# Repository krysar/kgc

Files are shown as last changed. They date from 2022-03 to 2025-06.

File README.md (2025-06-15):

# Kerbal Guidance Computer

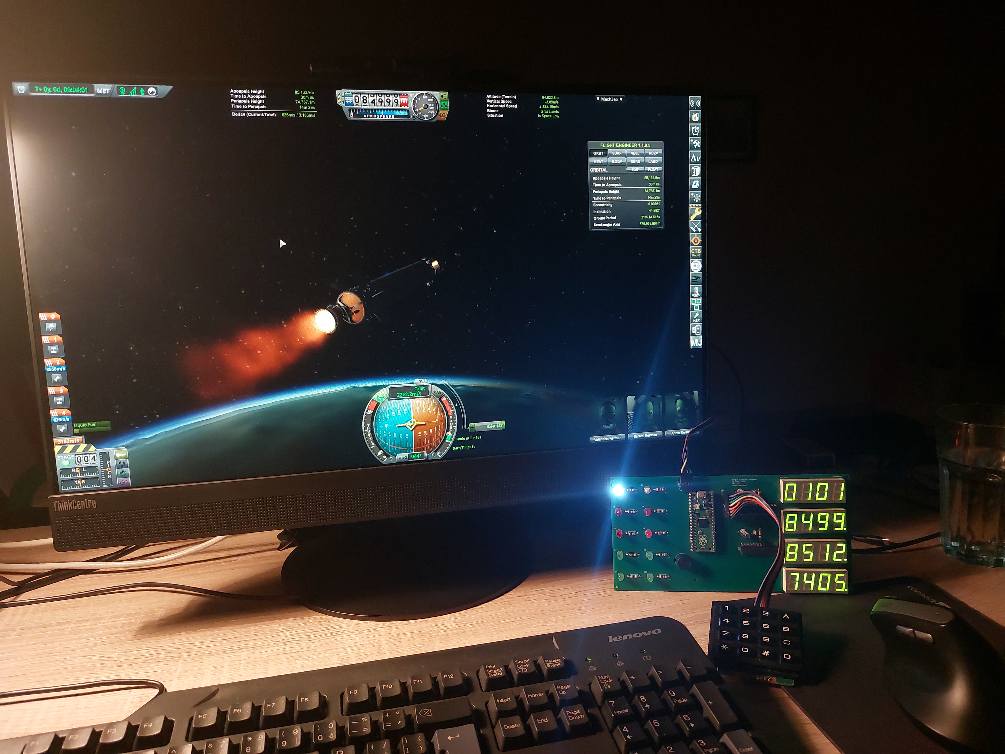
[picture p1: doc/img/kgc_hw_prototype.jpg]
KGC DSKY HW prototype of KGC's DSKY


A HW flight computer for Kerbal Space Program inspired by NASA's DSKY - interface for [Apollo Guidance Computer](https://en.wikipedia.org/wiki/Apollo_Guidance_Computer).

It consists of Python script for PC which grab data from the [kRPC mod](https://krpc.github.io/krpc/index.html), KGC's DSKY based on Raspberry Pi Pico and program for it. DSKY communicate with PC via UART, so you also need some USB-UART converter. KiCad project for DSKY is located in kicad directory.

**Project is still in developement, it's pretty buggy and some of planned features are stil unimplemented.**

## Features
### Implemented
- Display several flight informations depending on selected Verb and Noun.
- Ship control:
    - SAS control
    - RCS control
    - Gear control
    - Lights control
    - Brakes control
    - Solar panels control (extend/retract)
    - Antennas control (extend/retract)
    - Next stage activation
    - Abort group activation
- Maneuver planning
- MechJeb control:
    - Ascent guidance
### Planned
- Ship control:
    - Thrust control
- MechJeb control:
    - Landing guidance
    - Rendezvous autopilot
    - Docking autopilot
    - Maneuver planner

## Installation
TODO

## Usage
TODO

## Verbs and Nouns list

| Verb | Noun | Input/Output | Actions | Notes |
|---|---|---|---|---|
| 00 | 00 | | No op | |
| 01 | 01 | | Disconnect from server | |
| 00 | 02 | | Reboot | |
| 01 | 00 | | No op | |
| 01 | 01 | O: Altitude above sea level [m] | | |
| | | O: Apoapsis [m] | | |
| | | O: Periapsis [m] | | |
| 01 | 02 | O: Orbital inclination [°] | | |
| | | O: Orbital eccentricity [°] | | |
| | | O: Mean anomaly [°] | | |
| 01 | 03 | O: Time to apoapsis [hrs] | | |
| | | O: Time to apoapsis [min] | | |
| | | O: Time to apoapsis [sec] | | |
| 01 | 04 | O: Time to apoapsis [days] | | |
| | | O: Time to apoapsis [hrs] | | |
| | | O: Time to apoapsis [min] | | Kerbin days |
| 01 | 05 | O: Time to periapsis [hrs] | | |
| | | O: Time to periapsis [min] | | |
| | | O: Time to periapsis [sec] | | |
| 01 | 06 | O: Time to periapsis [days] | | |
| | | O: Time to periapsis [hrs] | | |
| | | O: Time to periapsis [min] | | Kerbin days |
| 01 | 07 | O: Orbital period [hrs] | | |
| | | O: Orbital period [min] | | |
| | | O: Orbital period [sec] | | |
| 01 | 08 | O: Orbital period [days] | | |
| | | O: Orbital period [hrs] | | |
| | | O: Orbital period [min] | | Kerbin days |
| 01 | 09 | O: Time to sphere of influence change [hrs]  | | |
| | | O: Time to sphere of influence change [min]  | | |
| | | O: Time to sphere of influence change [sec]  | | |
| 01 | 10 | O: Time to sphere of influence change [days] | | |
| | | O: Time to sphere of influence change [hrs]  | | |
| | | O: Time to sphere of influence change [min]  | | Kerbin days |
| 01 | 11 | O: Heading [°] | | TODO: check ref. frame |
| | | O: Pitch [°] | | TODO: check ref. frame |
| | | O: Roll [°] | | TODO: check ref. frame |
| 01 | 12 | O: Velocity - x [m/s] | | TODO: check ref. frame |
| | | O: Velocity - y [m/s] | | |
| | | O: Velocity - z [m/s] | | |
| 01 | 13 | O: Orbital speed [m/s] | | |
| | | O: Surface speed [m/s] | | |
| 02 | 00 | | No op | |
| 02 | 01 | O: Mission elapsed time [hrs] | | |
| | | O: Mission elapsed time [min] | | |
| | | O: Mission elapsed time [sec] | | Strange bug |
| 02 | 02 | O: Mission elapsed time [days] | | |
| | | O: Mission elapsed time [min] | | Strange bug |
| | | O: Mission elapsed time [hrs] | | Strange bug |
| 02 | 03 | O: Mass [kg] | | |
| | | O: Available thurst [N] | | |
| | | O: Specific impulse [sec] | | |
| 02 | 04 | O: Electric charge capacity [-] | | |
| | | O: Monopropellant capacity [-] | | |
| | | O: Liquid fuel capacity [-] | | |
| 02 | 05 | O: Electric charge amount [-] | | TODO: float |
| | | O: Monopropellant amount [-] | | TODO: float |
| | | O: Liquid fuel amount [-] | | TODO: float |
| 02 | 06 | O: Electric charge amount [%] | | |
| | | O: Monopropellant amount [%] | | |
| | | O: Liquid fuel amount [%] | | |
| 02 | 07 | O: Electric charge capacity [-] | | |
| | | O: Electric charge amount [-] | | TODO: float |
| | | O: Electric charge amount [%] | | |
| 02 | 08 | O: Monopropellant capacity [-] | | |
| | | O: Monopropellant amount [-] | | TODO: float |
| | | O: Monopropellant amount [%] | | |
| 02 | 09 | O: Liquid fuel capacity [-] | | |
| | | O: Liquid fuel amount [-] | | TODO: float |
| | | O: Liquid fuel amount [%] | | |
| 03 | 01 | O: Surface speed [m/s] | | |
| | | O: Vertical speed [m/s] | | |
| | | O: Altitude above surface [m] | | |
| 03 | 02 | O: Altitude above sea level | | |
| | | O: Apoapsis [m] | | |
| | | O: Orbital inclination [°] | | |
| 03 | 03 | O: Apoapsis [m] | | |
| | | O: Periapsis [m] | | |
| | | O: Orbital inclination [°] | | |
| 04 | 01 | O: Time to node [hrs] | | |
| | | O: Time to node [min] | | |
| | | O: Time to node [sec] | | |
| 04 | 02 | O: Δv magnitude - prograde direction [m/s] | | |
| | | O: Δv magnitude - normal direction [m/s] | | |
| | | O: Δv magnitude - radial direction [m/s] | | |
| 04 | 03 | O: Δv [m/s] | | |
| | | O: Remaining Δv [m/s] | | |
| | | O: Time to node [sec] | | |
| 04 | 04 | O: Result apoapsis [m] | | |
| | | O: Result periapsis [m] | | |
| | | O: Result inclination [°] | | |
| 05 | 01 | O: Altitude above surface [m] | | |
| | | O: Surface speed [m/s] | | |
| | | O: Liquid fuel amount [%] | | |
| 05 | 02 | O: Altitude above surface [m] | | |
| | | O: Vertical speed [m/s] | | |
| | | O: Horizontal speed [m/s] | | |
| 12 | 01 | | Activate SAS in stability assist mode | Then return to previous Verb + Noun |
| 12 | 02 | | Activate SAS in maneuver mode | Then return to previous Verb + Noun |
| 12 | 03 | | Activate SAS in prograde mode | Then return to previous Verb + Noun |
| 12 | 04 | | Activate SAS in retrograde mode | Then return to previous Verb + Noun |
| 12 | 05 | | Activate SAS in normal mode | Then return to previous Verb + Noun |
| 12 | 06 | | Activate SAS in anti-normal mode | Then return to previous Verb + Noun |
| 12 | 07 | | Activate SAS in radial mode | Then return to previous Verb + Noun |
| 12 | 08 | | Activate SAS in anti-radial mode | Then return to previous Verb + Noun |
| 12 | 09 | | Activate SAS in target mode | Then return to previous Verb + Noun |
| 12 | 10 | | Activate SAS in anti-targer mode | Then return to previous Verb + Noun |
| 12 | 11 | | Deactivate SAS | Then return to previous Verb + Noun |
| 12 | 12 | | Activate RCS | Then return to previous Verb + Noun |
| 12 | 13 | | Deactivate RCS | Then return to previous Verb + Noun |
| 12 | 14 | | Extend gear | Then return to previous Verb + Noun |
| 12 | 15 | | Retract gear | Then return to previous Verb + Noun |
| 12 | 16 | | Activate ligts | Then return to previous Verb + Noun |
| 12 | 17 | | Deactivate lights | Then return to previous Verb + Noun |
| 12 | 18 | | Activate brakes | Then return to previous Verb + Noun |
| 12 | 19 | | Deactivate brakes | Then return to previous Verb + Noun |
| 12 | 20 | | Extend solar panels | Then return to previous Verb + Noun |
| 12 | 21 | | Retract solar panels | Then return to previous Verb + Noun |
| 12 | 22 | | Extend antennas | Then return to previous Verb + Noun |
| 12 | 23 | | Retract antennas | Then return to previous Verb + Noun |
| 12 | 24 | | Activate next stage | Then return to previous Verb + Noun |
| 12 | 25 | | Activate abort group | Then return to previous Verb + Noun |
| 12 | 30 | | Initialize node creation | |
| 12 | 31 | I: UT - year | | |
| | | I: UT - day | | |
| 12 | 32 | O: UT - year | | |
| | | O: UT - day | | |
| 12 | 33 | I: UT - hour | | |
| | | I: UT - minute | | |
| | | I: UT - second | | |
| 12 | 34 | O: UT - hour | | |
| | | O: UT - minute | | |
| | | O: UT - second | | |
| 12 | 35 | I: Δv - prograde [m/s] | | |
| | | I: Δv - normal [m/s] | | |
| | | I: Δv - radial [m/s] | | |
| 12 | 36 | O: Δv - prograde [m/s] | | |
| | | O: Δv - normal [m/s] | | |
| | | O: Δv - radial [m/s] | | |
| 12 | 37 | | Create node | Incorrect time |
| 13 | 00 | | Initialize ascent autpoilot | MechJeb is used |
| 13 | 01 | I: Orbit altitude [km] | | |
| | | I: Orbit inclination [°] | | |
| | | I: Ascent profile {1; 2; 3} | | 1 = Classic ascent profile |
| | | | | 2 = Stock-style GravityTurn ascent profile |
| | | | | 3 = Primer Vector Guidance ascent profile |
| 13 | 02 | O: Orbit altitude [km] | | |
| | | O: Orbit inclination [°] | | |
| | | O: Ascent profile {1; 2; 3} | | |
| 13 | 03 | I: Acceleration limit [m/s] | | -1 for disable; -2 for ignore |
| | | I: Throttle limit [%] | | -1 for disable; -2 for ignore |
| 13 | 04 | O: Acceleration limit [m/s] | | |
| | | O: Throttle limit [%] | | |
| 13 | 05 | I: Force roll - climb [°] | | -1 for disable; -2 for ignore (whole force roll) |
| | | I: Force roll - turn [°] | | |
| 13 | 06 | O: Force roll - climb [°] | | |
| | | O: Force roll - turn [°] | | |
| 13 | 07 | I: Autostage pre-delay [s] | | -1 for disable; -2 for ignore (whole autostage) |
| | | I: Autostage post-delay [s] | | |
| | | I: Clamp autostage thrust [%] | | |
| 13 | 08 | O: Autostage pre-delay [s] | | |
| | | O: Autostage post-delay [s] | | |
| | | O: Clamp autostage thrust [%] | | |
| 13 | 09 | I: Minimal throttle [%] | | -1 for disable; -2 for ignore |
| | | I: Autostage stop stage | | Details in truth table |
| | | I: Other options | | |
| 13 | 10 | O: Minimal throttle [%] | | |
| | | O: Autostage stop stage | | |
| | | O: Other options | | |
| 13 | 11 | I: Turn start altitude [km] | | Classic ascent profile |
| | | I: Turn start velocity [m/s] | | Classic ascent profile |
| | | I: Turn end altitude [km] | | Classic ascent profile |
| 13 | 12 | O: Turn start altitude [km] | | Classic ascent profile |
| | | O: Turn start velocity [m/s] | | Classic ascent profile |
| | | O: Turn end altitude [km] | | Classic ascent profile |
| 13 | 13 | I: Final flight path angle [°] | | Classic ascent profile; -1 for disable; -2 for ignore |
| | | I: Turn shape [%] | | Classic ascent profile; -1 for disable; -2 for ignore |
| 13 | 14 | O: Final flight path angle [°] | | Classic ascent profile |
| | | O: Turn shape [%] | | Classic ascent profile |
| 13 | 15 | I: Turn start altitude [km] | | Stock-style GravityTurn ascent profile |
| | | I: Turn start velocity [m/s] | | Stock-style GravityTurn ascent profile |
| | | I: Turn start pitch [°] | | Stock-style GravityTurn ascent profile |
| 13 | 16 | O: Turn start altitude [km] | | Stock-style GravityTurn ascent profile |
| | | O: Turn start velocity [m/s] | | Stock-style GravityTurn ascent profile |
| | | O: Turn start pitch [°] | | Stock-style GravityTurn ascent profile |
| 13 | 17 | I: Intermediate altitude [km] | | Stock-style GravityTurn ascent profile |
| | | I: Hold AP time [s] | | Stock-style GravityTurn ascent profile |
| 13 | 18 | O: Intermediate altitude [km] | | Stock-style GravityTurn ascent profile |
| | | O: Hold AP time [s] | | Stock-style GravityTurn ascent profile |
| 13 | 19 | I: Apoapsis altitude [km] | | Primer Vector Guidance ascent profile |
| | | I: Attach altitude [km] | | Primer Vector Guidance ascent profile |
| | | I: Booster pitch start velocity [m/s] | | Primer Vector Guidance ascent profile |
| 13 | 20 | O: Apoapsis altitude [km] | | Primer Vector Guidance ascent profile |
| | | O: Attach altitude [km] | | Primer Vector Guidance ascent profile |
| | | O: Booster pitch start velocity [m/s] | | Primer Vector Guidance ascent profile |
| 13 | 21 | I: Booster pitch rate [°/s] | | Primer Vector Guidance ascent profile |
| | | I: PVG after stage | | Primer Vector Guidance ascent profile; -1 for disable; -2 for ignore |
| 13 | 22 | O: Booster pitch rate [°/s] | | Primer Vector Guidance ascent profile |
| | | O: PVG after stage | | Primer Vector Guidance ascent profile |
| 13 | 23 | I: Q trigger [kPa] | | Primer Vector Guidance ascent profile |
| | | I: Fixed coast length [s] | | Primer Vector Guidance ascent profile; -1 for disable; -2 for ignore |
| 13 | 24 | O: Q trigger [kPa] | | Primer Vector Guidance ascent profile |
| | | O: Fixed coast length [s] | | Primer Vector Guidance ascent profile |
| 13 | 25 | | Enage ascent autopilot | |
| 13 | 26 | | Disenage ascent autopilot | |

## Truth table for other options value in Ascent autopilot

| Prevent overheat | Solar panels | Antennas | Skip circularization | Dec |
|---|---|---|---|-----|
| 0 | 0 | 0 | 0 | 0 |
| 0 | 0 | 0 | 1 | 1 |
| 0 | 0 | 1 | 0 | 2 |
| 0 | 0 | 1 | 1 | 3 |
| 0 | 1 | 0 | 0 | 4 |
| 0 | 1 | 0 | 1 | 5 |
| 0 | 1 | 1 | 0 | 6 |
| 0 | 1 | 1 | 1 | 7 |
| 1 | 0 | 0 | 0 | 8 |
| 1 | 0 | 0 | 1 | 9 |
| 1 | 0 | 1 | 0 | 10  |
| 1 | 0 | 1 | 1 | 11  |
| 1 | 1 | 0 | 0 | 12  |
| 1 | 1 | 0 | 1 | 13  |
| 1 | 1 | 1 | 0 | 14  |
| 1 | 1 | 1 | 1 | 15  |

## Error codes
### Ascent guidance:
- 1301: Noun doesn't exist
- 1302: Autopilot wasn't initialized
- 1303: Ascent profile selected in V13;N01 doesn't exist

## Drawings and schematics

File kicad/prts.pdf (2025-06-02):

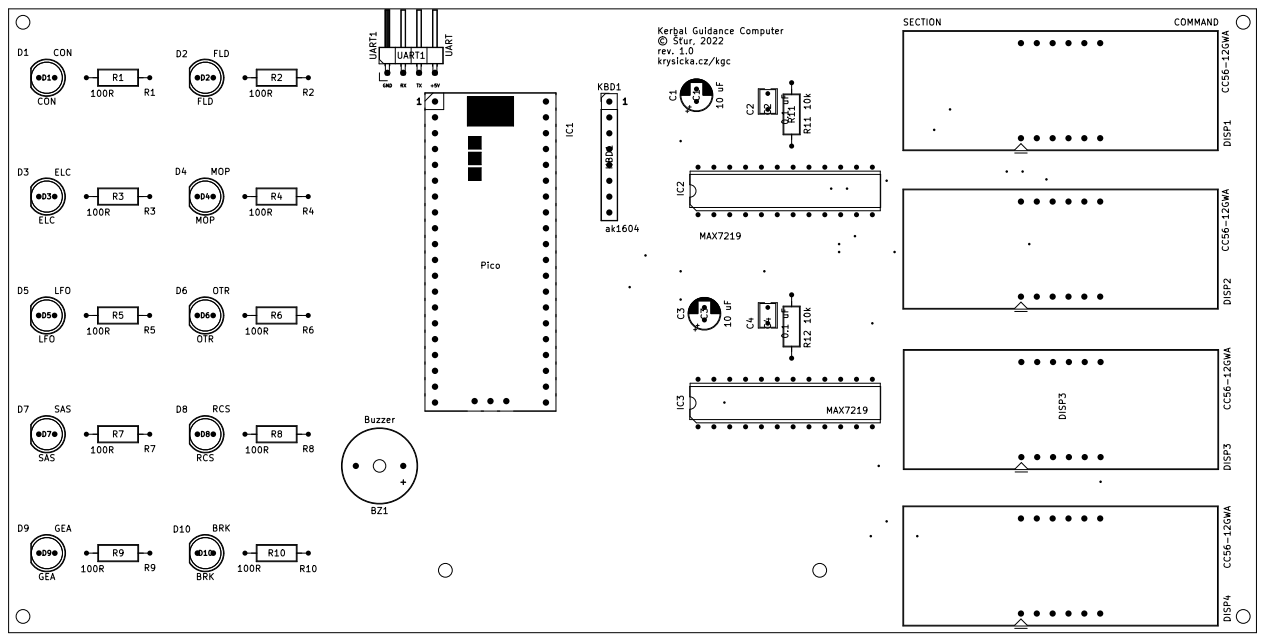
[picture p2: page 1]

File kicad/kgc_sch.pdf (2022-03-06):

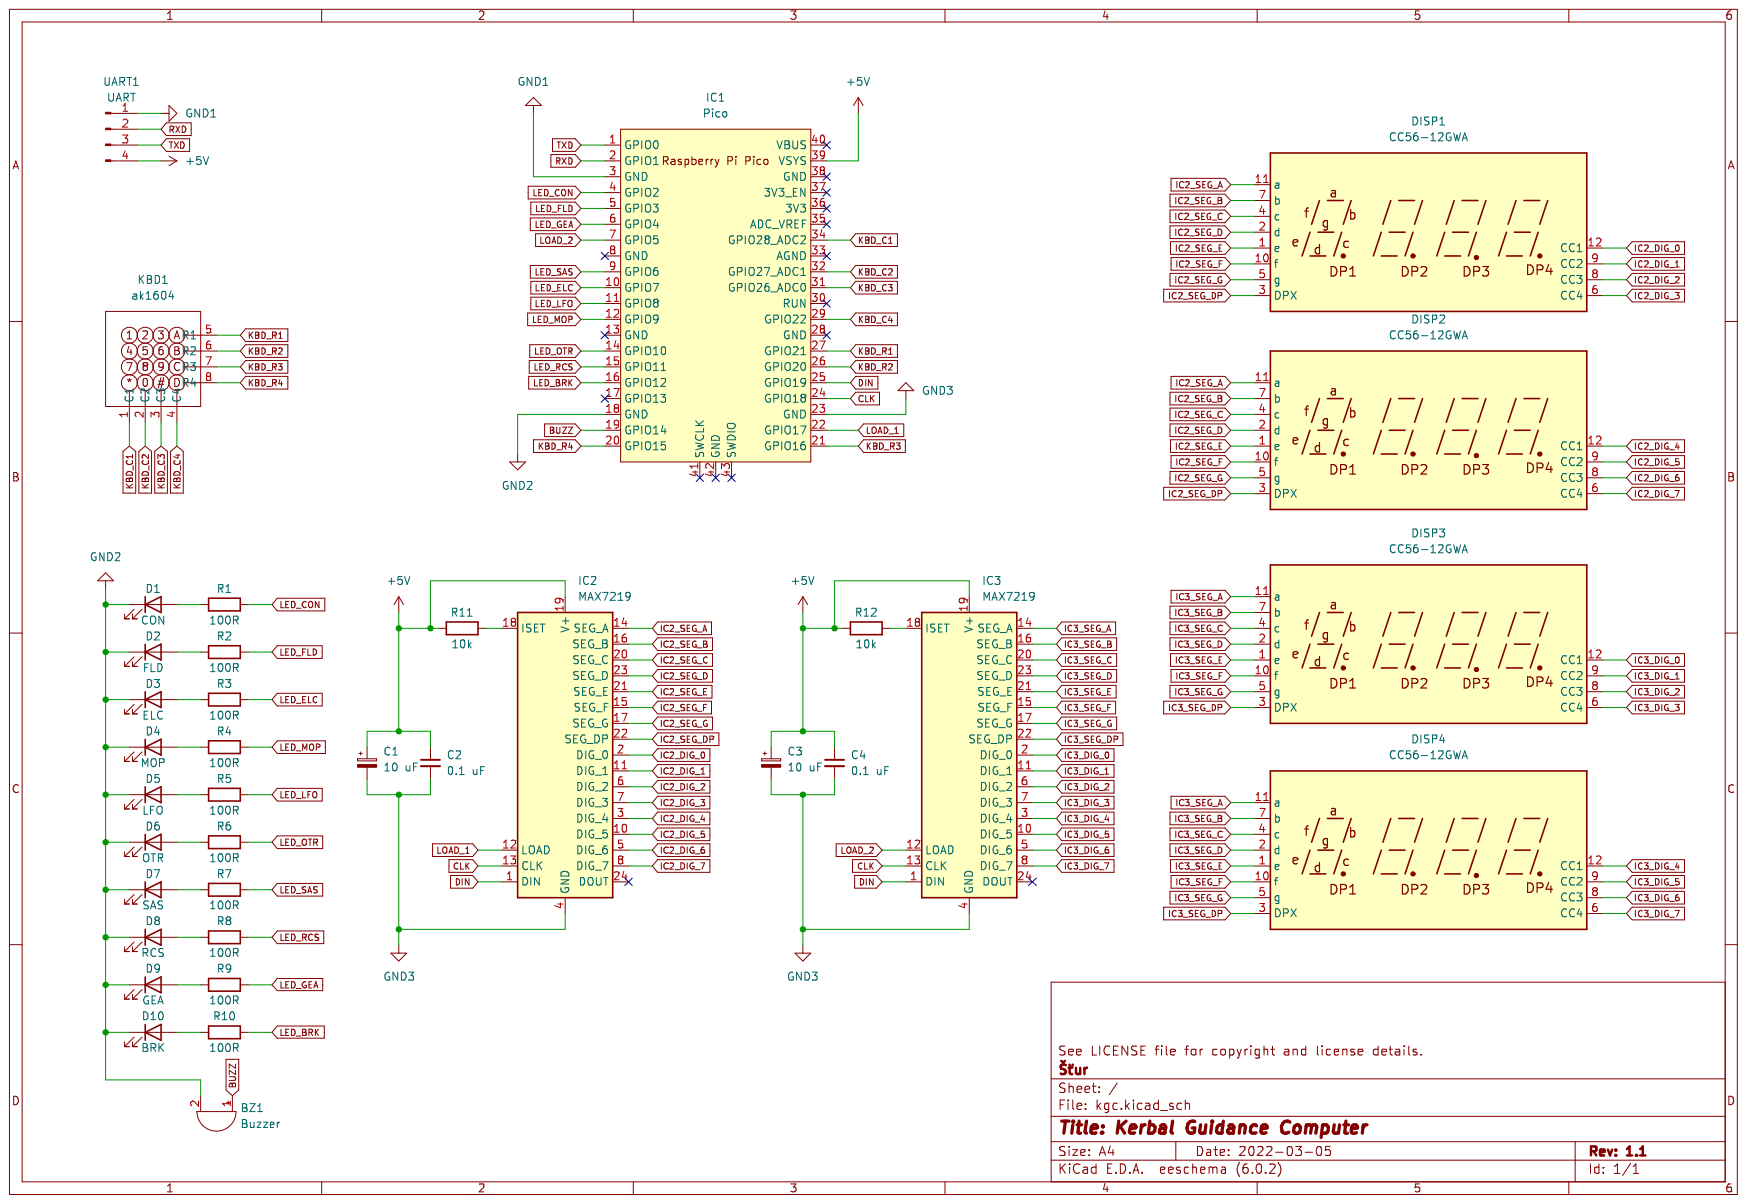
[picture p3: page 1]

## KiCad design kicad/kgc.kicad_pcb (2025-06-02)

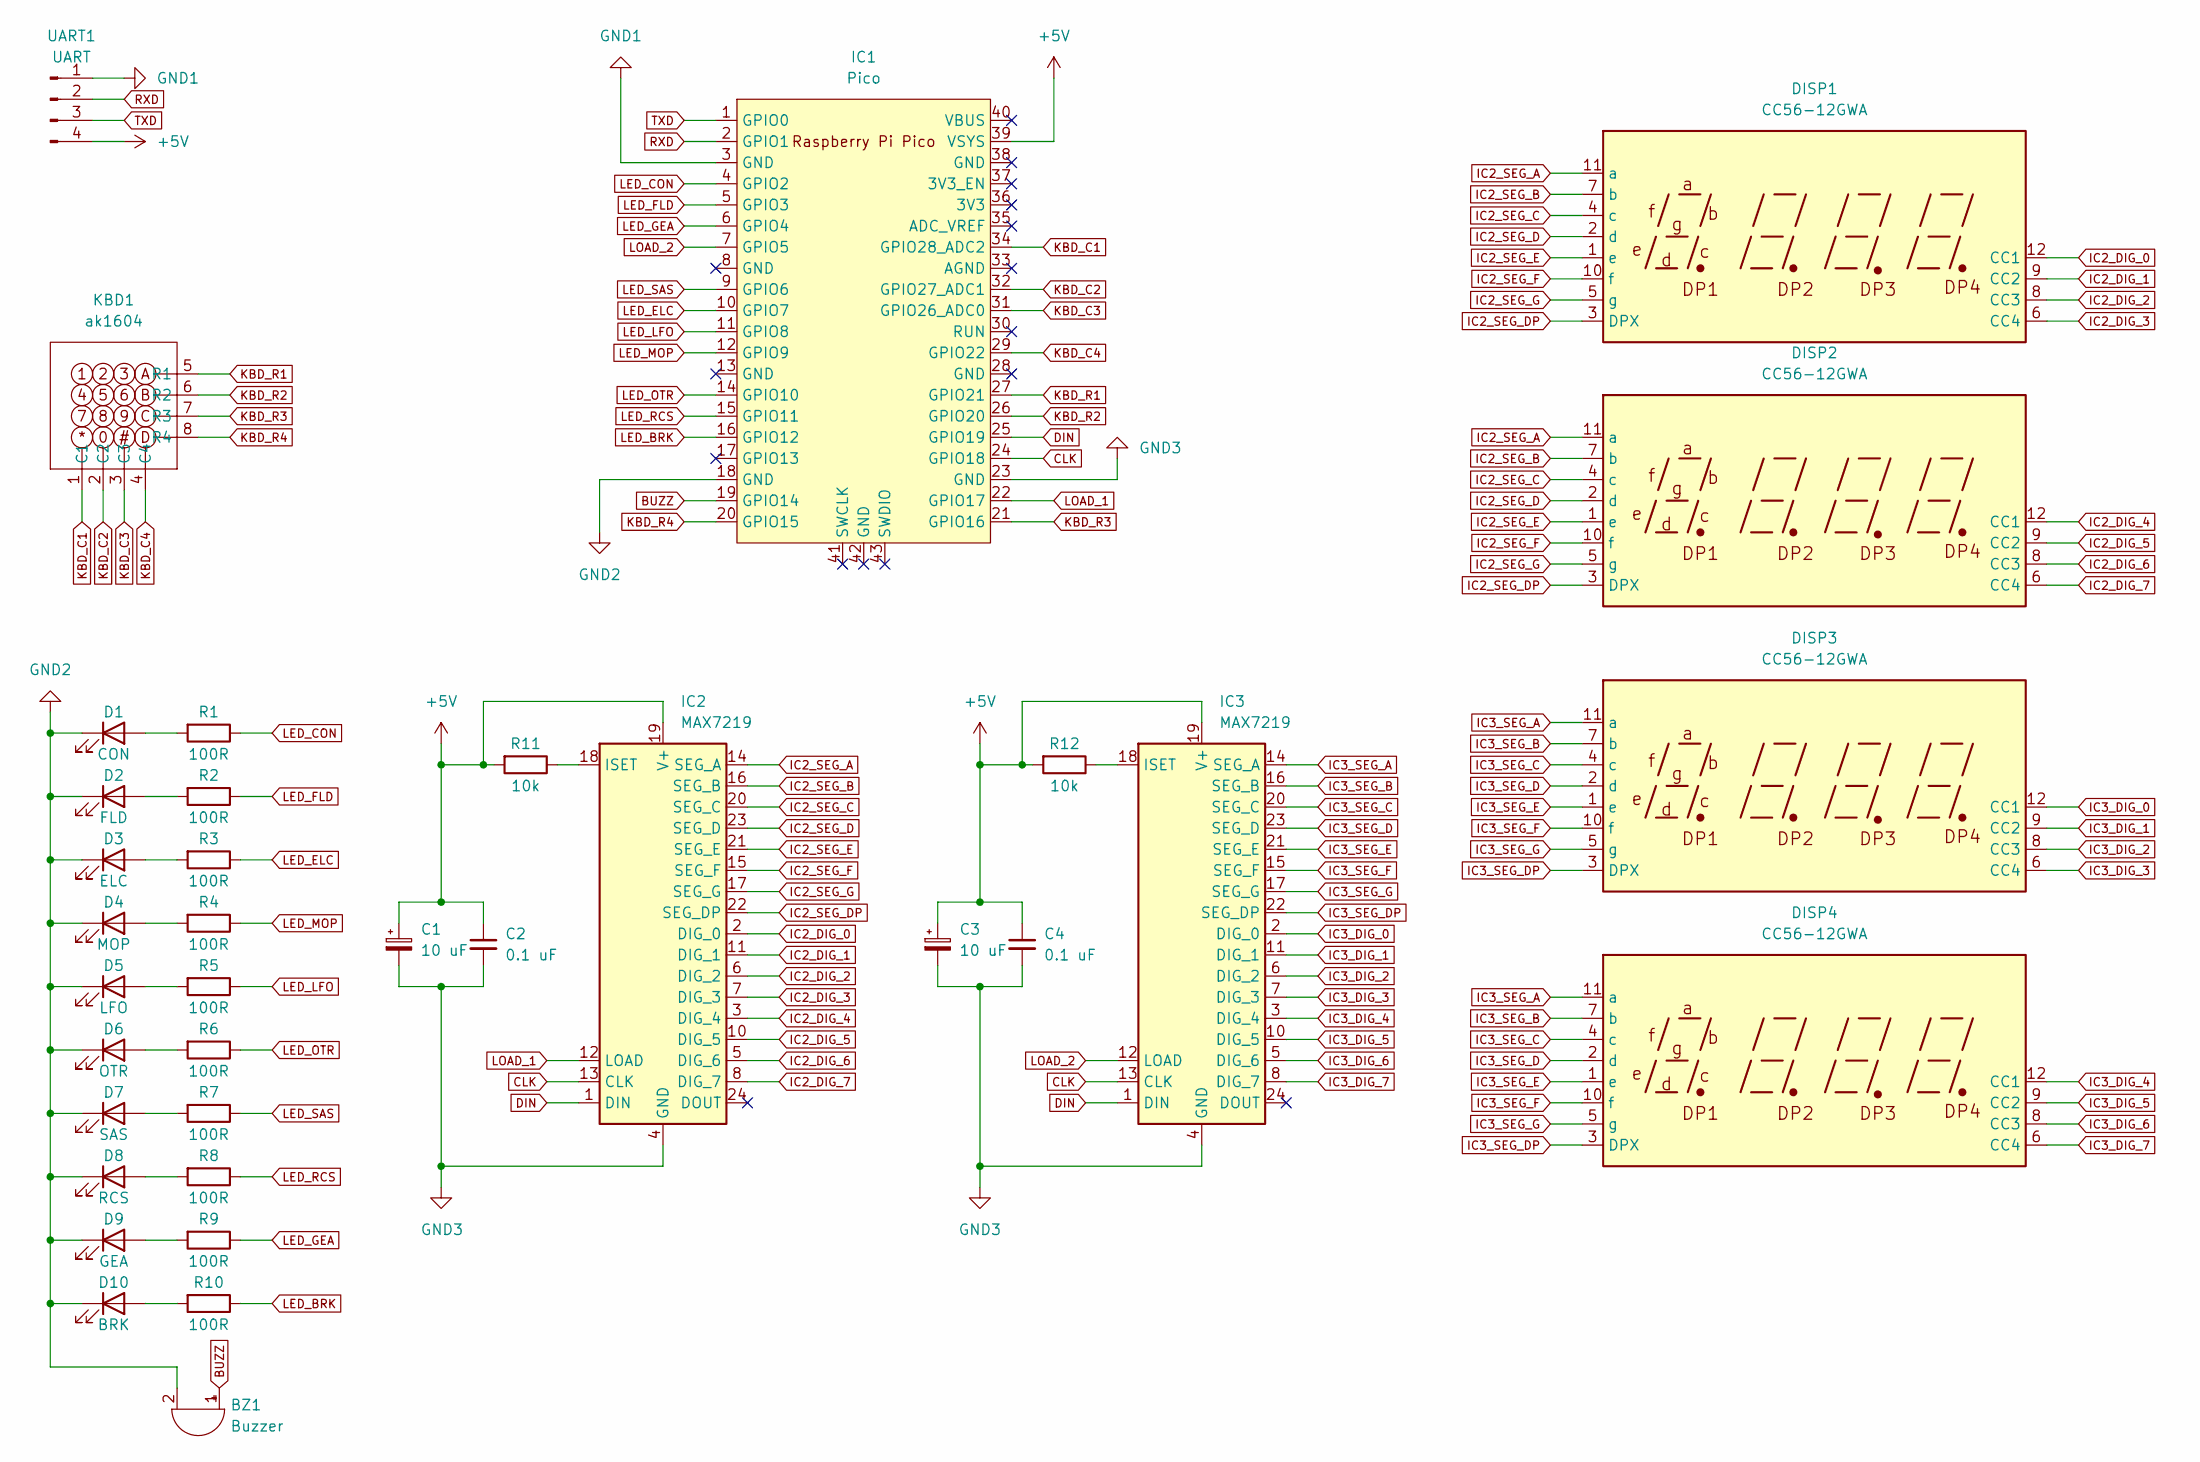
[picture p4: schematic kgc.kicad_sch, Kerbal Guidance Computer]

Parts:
BZ1: Buzzer; Buzzer_12x9.5RM7.6
C1, C3: 10 uF; CP_Radial_D5.0mm_P2.00mm
C2, C4: 0.1 uF; C31x
D1: CON; LED_D5.0mm
D2: FLD; LED_D5.0mm
D3: ELC; LED_D5.0mm
D4: MOP; LED_D5.0mm
D5: LFO; LED_D5.0mm
D6: OTR; LED_D5.0mm
D7: SAS; LED_D5.0mm
D8: RCS; LED_D5.0mm
D9: GEA; LED_D5.0mm
D10: BRK; LED_D5.0mm
DISP1, DISP2, DISP3, DISP4: CC56-12GWA
IC1: Pico; RPi_Pico_TH
IC2, IC3: MAX7219; DIP-24_W7.62mm
KBD1: ak1604; PinHeader_1x08_P2.54mm_Vertical
R1, R2, R3, R4, R5, R6, R7, R8, R9, R10: 100R; R_Axial_DIN0207_L6.3mm_D2.5mm_P10.16mm_Horizontal
R11, R12: 10k; R_Axial_DIN0207_L6.3mm_D2.5mm_P10.16mm_Horizontal
UART1: UART; PinHeader_1x04_P2.54mm_Horizontal

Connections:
+5V: C1.1, C2.1, C3.1, C4.1, IC1.39 (VSYS), IC2.19 (V+), IC3.19 (V+), R11.2, R12.2, UART1.4
BUZZ: BZ1.1 (-), IC1.19 (GPIO14)
CLK: IC1.24 (GPIO18), IC2.13 (CLK), IC3.13 (CLK)
DIN: IC1.25 (GPIO19), IC2.1 (DIN), IC3.1 (DIN)
GND1: IC1.3 (GND), UART1.1
GND2: BZ1.2 (+), D1.1 (K), D2.1 (K), D3.1 (K), D4.1 (K), D5.1 (K), D6.1 (K), D7.1 (K), D8.1 (K), D9.1 (K), D10.1 (K), IC1.18 (GND)
GND3: C1.2, C2.2, C3.2, C4.2, IC1.23 (GND), IC2.4 (GND), IC2.9 (GND), IC3.4 (GND), IC3.9 (GND)
IC2_DIG_0: DISP1.12 (CC1), IC2.2 (DIG_0)
IC2_DIG_1: DISP1.9 (CC2), IC2.11 (DIG_1)
IC2_DIG_2: DISP1.8 (CC3), IC2.6 (DIG_2)
IC2_DIG_3: DISP1.6 (CC4), IC2.7 (DIG_3)
IC2_DIG_4: DISP2.12 (CC1), IC2.3 (DIG_4)
IC2_DIG_5: DISP2.9 (CC2), IC2.10 (DIG_5)
IC2_DIG_6: DISP2.8 (CC3), IC2.5 (DIG_6)
IC2_DIG_7: DISP2.6 (CC4), IC2.8 (DIG_7)
IC2_SEG_A: DISP1.11 (a), DISP2.11 (a), IC2.14 (SEG_A)
IC2_SEG_B: DISP1.7 (b), DISP2.7 (b), IC2.16 (SEG_B)
IC2_SEG_C: DISP1.4 (c), DISP2.4 (c), IC2.20 (SEG_C)
IC2_SEG_D: DISP1.2 (d), DISP2.2 (d), IC2.23 (SEG_D)
IC2_SEG_DP: DISP1.3 (DPX), DISP2.3 (DPX), IC2.22 (SEG_DP)
IC2_SEG_E: DISP1.1 (e), DISP2.1 (e), IC2.21 (SEG_E)
IC2_SEG_F: DISP1.10 (f), DISP2.10 (f), IC2.15 (SEG_F)
IC2_SEG_G: DISP1.5 (g), DISP2.5 (g), IC2.17 (SEG_G)
IC3_DIG_0: DISP3.12 (CC1), IC3.2 (DIG_0)
IC3_DIG_1: DISP3.9 (CC2), IC3.11 (DIG_1)
IC3_DIG_2: DISP3.8 (CC3), IC3.6 (DIG_2)
IC3_DIG_3: DISP3.6 (CC4), IC3.7 (DIG_3)
IC3_DIG_4: DISP4.12 (CC1), IC3.3 (DIG_4)
IC3_DIG_5: DISP4.9 (CC2), IC3.10 (DIG_5)
IC3_DIG_6: DISP4.8 (CC3), IC3.5 (DIG_6)
IC3_DIG_7: DISP4.6 (CC4), IC3.8 (DIG_7)
IC3_SEG_A: DISP3.11 (a), DISP4.11 (a), IC3.14 (SEG_A)
IC3_SEG_B: DISP3.7 (b), DISP4.7 (b), IC3.16 (SEG_B)
IC3_SEG_C: DISP3.4 (c), DISP4.4 (c), IC3.20 (SEG_C)
IC3_SEG_D: DISP3.2 (d), DISP4.2 (d), IC3.23 (SEG_D)
IC3_SEG_DP: DISP3.3 (DPX), DISP4.3 (DPX), IC3.22 (SEG_DP)
IC3_SEG_E: DISP3.1 (e), DISP4.1 (e), IC3.21 (SEG_E)
IC3_SEG_F: DISP3.10 (f), DISP4.10 (f), IC3.15 (SEG_F)
IC3_SEG_G: DISP3.5 (g), DISP4.5 (g), IC3.17 (SEG_G)
KBD_C1: IC1.34 (GPIO28_ADC2), KBD1.1 (C1)
KBD_C2: IC1.32 (GPIO27_ADC1), KBD1.2 (C2)
KBD_C3: IC1.31 (GPIO26_ADC0), KBD1.3 (C3)
KBD_C4: IC1.29 (GPIO22), KBD1.4 (C4)
KBD_R1: IC1.27 (GPIO21), KBD1.5 (R1)
KBD_R2: IC1.26 (GPIO20), KBD1.6 (R2)
KBD_R3: IC1.21 (GPIO16), KBD1.7 (R3)
KBD_R4: IC1.20 (GPIO15), KBD1.8 (R4)
LED_BRK: IC1.16 (GPIO12), R10.1
LED_CON: IC1.4 (GPIO2), R1.1
LED_ELC: IC1.10 (GPIO7), R3.1
LED_FLD: IC1.5 (GPIO3), R2.1
LED_GEA: IC1.6 (GPIO4), R9.1
LED_LFO: IC1.11 (GPIO8), R5.1
LED_MOP: IC1.12 (GPIO9), R4.1
LED_OTR: IC1.14 (GPIO10), R6.1
LED_RCS: IC1.15 (GPIO11), R8.1
LED_SAS: IC1.9 (GPIO6), R7.1
LOAD_1: IC1.22 (GPIO17), IC2.12 (LOAD)
LOAD_2: IC1.7 (GPIO5), IC3.12 (LOAD)
unnamed: D1.2 (A), R1.2
unnamed: D2.2 (A), R2.2
unnamed: D3.2 (A), R3.2
unnamed: D4.2 (A), R4.2
unnamed: D5.2 (A), R5.2
unnamed: D6.2 (A), R6.2
unnamed: D7.2 (A), R7.2
unnamed: D8.2 (A), R8.2
unnamed: D9.2 (A), R9.2
unnamed: D10.2 (A), R10.2
unnamed: IC2.18 (ISET), R11.1
unnamed: IC3.18 (ISET), R12.1
RXD: IC1.2 (GPIO1), UART1.2
TXD: IC1.1 (GPIO0), UART1.3

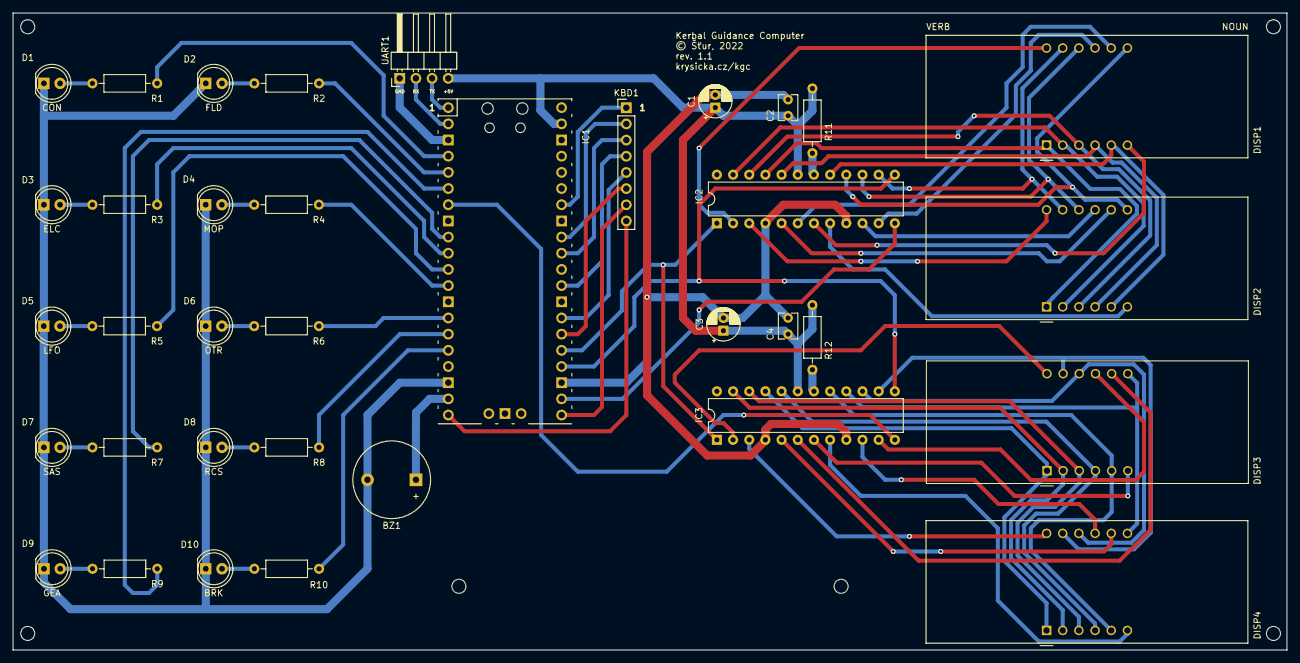
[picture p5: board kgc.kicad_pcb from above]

Board: 2 copper layers, 200.0 x 100.0 mm, 36 parts (0 on the bottom side), 73 nets.

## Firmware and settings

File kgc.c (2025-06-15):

#include <stdio.h>
#include <stdlib.h>
#include <math.h>
#include <time.h>
#include <string.h>

#include "pico/stdlib.h"
#include "pico/binary_info.h"
#include "hardware/spi.h"
#include "hardware/gpio.h"
#include "pico/multicore.h"
#include "hardware/irq.h"
#include "hardware/watchdog.h"

#include "max7219.h"
#include "keypad.h"
#include "connection.h"
#include "led.h"
#include "errors.h"

#define NOD_INS_3_NUMS(prev) {\
    if((prev_verb == 12) && (prev_noun == prev)) { \
        SAVE_PREV_VERB_NOUN \
\
        clear_display(0, 1); \
        clear_display(1, 0); \
        clear_display(1, 1); \
\
        sleep_ms(500); \
\
        insnms[0] = request_number(0, 1); \
        insnms[1] = request_number(1, 0); \
        insnms[2] = request_number(1, 1); \
\
        sleep_ms(100); \
\
        send_data[0] = insnms[0]; \
        send_data[1] = insnms[1]; \
        send_data[2] = insnms[2]; \
\
        sleep_ms(1500); \
\
        noun = prev + 2; \
        send_data[0] = -2; \
        send_data[1] = -2; \
        send_data[2] = -2; \
        clear_display(0, 0); \
        add_alarm_in_ms(800, display_program, NULL, false); /* 800 ms blank, then display program */ \
        sleep_ms(900); \
    } else { \
        while(keypad_status != KEY_STAT_PRG_CHANGE) { \
            flight_data = uart_data_decoder(uart_str_in); \
            led_update(flight_data); \
            clear_display(0, 1); \
            display_err_code(ERR_NOD_UNINITIALIZED); \
        } \
    } \
}

#define NOD_INS_2_NUMS(prev) {\
    if((prev_verb == 12) && (prev_noun == prev)) { \
        SAVE_PREV_VERB_NOUN \
\
        clear_display(0, 1); \
        clear_display(1, 0); \
        clear_display(1, 1); \
\
        sleep_ms(500); \
\
        insnms[0] = request_number(0, 1); \
        insnms[1] = request_number(1, 0); \
\
        sleep_ms(100); \
\
        send_data[0] = insnms[0]; \
        send_data[1] = insnms[1]; \
        send_data[2] = -2; \
\
        sleep_ms(1500); \
\
        noun = prev + 2; \
        send_data[0] = -2; \
        send_data[1] = -2; \
        send_data[2] = -2; \
        clear_display(0, 0); \
        add_alarm_in_ms(800, display_program, NULL, false); /* 800 ms blank, then display program */ \
        sleep_ms(900); \
    } else { \
        while(keypad_status != KEY_STAT_PRG_CHANGE) { \
            flight_data = uart_data_decoder(uart_str_in); \
            led_update(flight_data); \
            clear_display(0, 1); \
            display_err_code(ERR_NOD_UNINITIALIZED); \
        } \
    } \
}

#define NOD_DISP_3_NUMS(prev) {\
    if((prev_verb == 12) && (prev_noun == prev)) { \
        SAVE_PREV_VERB_NOUN \
        led_stat[LED_STAT_DISP1] = true;\
        keypad_status = KEY_STAT_NO_CHANGE;\
        while(keypad_status != KEY_STAT_PROCEED) { \
            flight_data = uart_data_decoder(uart_str_in); \
            led_update(flight_data); \
            display_number(0, 1, flight_data.num1); \
            display_number(1, 0, flight_data.num2); \
            display_number(1, 1, flight_data.num3); \
        } \
\
        led_stat[LED_STAT_DISP1] = false;\
        noun = prev + 2; \
        clear_display(0, 0); \
        add_alarm_in_ms(800, display_program, NULL, false); /* 800 ms blank, then display program */ \
        sleep_ms(900); \
    } else { \
        while(keypad_status != KEY_STAT_PRG_CHANGE) { \
            flight_data = uart_data_decoder(uart_str_in); \
            led_update(flight_data); \
            clear_display(0, 1); \
            display_err_code(ERR_NOD_UNINITIALIZED); \
        } \
    } \
}

#define NOD_DISP_2_NUMS(prev) {\
    if((prev_verb == 12) && (prev_noun == prev)) { \
        SAVE_PREV_VERB_NOUN \
        led_stat[LED_STAT_DISP1] = true;\
        keypad_status = KEY_STAT_NO_CHANGE;\
        while(keypad_status != KEY_STAT_PROCEED) { \
            flight_data = uart_data_decoder(uart_str_in); \
            led_update(flight_data); \
            display_number(0, 1, flight_data.num1); \
            display_number(1, 0, flight_data.num2); \
            clear_display(1, 1); \
        } \
\
        led_stat[LED_STAT_DISP1] = false;\
        noun = prev + 2; \
        clear_display(0, 0); \
        add_alarm_in_ms(800, display_program, NULL, false); /* 800 ms blank, then display program */ \
        sleep_ms(900); \
    } else { \
        while(keypad_status != KEY_STAT_PRG_CHANGE) { \
            flight_data = uart_data_decoder(uart_str_in); \
            led_update(flight_data); \
            clear_display(0, 1); \
            display_err_code(ERR_NOD_UNINITIALIZED); \
        } \
    } \
}

#define ASC_INS_3_NUMS(prev, next) {\
    if((prev_verb == 13) && (prev_noun == prev)) { \
        SAVE_PREV_VERB_NOUN \
\
        clear_display(0, 1); \
        clear_display(1, 0); \
        clear_display(1, 1); \
\
        sleep_ms(500); \
\
        insnms[0] = request_number(0, 1); \
        insnms[1] = request_number(1, 0); \
        insnms[2] = request_number(1, 1); \
\
        sleep_ms(100); \
\
        send_data[0] = insnms[0]; \
        send_data[1] = insnms[1]; \
        send_data[2] = insnms[2]; \
\
        sleep_ms(1500); \
\
        noun = next; \
        send_data[0] = -2; \
        send_data[1] = -2; \
        send_data[2] = -2; \
        clear_display(0, 0); \
        add_alarm_in_ms(800, display_program, NULL, false); /* 800 ms blank, then display program */ \
        sleep_ms(900); \
    } else { \
        while(keypad_status != KEY_STAT_PRG_CHANGE) { \
            flight_data = uart_data_decoder(uart_str_in); \
            led_update(flight_data); \
            clear_display(0, 1); \
            display_err_code(ERR_ASC_UNINITIALIZED); \
        } \
    } \
}

#define ASC_INS_2_NUMS(prev, next) {\
    if((prev_verb == 13) && (prev_noun == prev)) { \
        SAVE_PREV_VERB_NOUN \
\
        clear_display(0, 1); \
        clear_display(1, 0); \
        clear_display(1, 1); \
\
        sleep_ms(500); \
\
        insnms[0] = request_number(0, 1); \
        insnms[1] = request_number(1, 0); \
\
        sleep_ms(100); \
\
        send_data[0] = insnms[0]; \
        send_data[1] = insnms[1]; \
        send_data[2] = -2; \
\
        sleep_ms(1500); \
\
        noun = next; \
        send_data[0] = -2; \
        send_data[1] = -2; \
        send_data[2] = -2; \
        clear_display(0, 0); \
        add_alarm_in_ms(800, display_program, NULL, false); /* 800 ms blank, then display program */ \
        sleep_ms(900); \
    } else { \
        while(keypad_status != KEY_STAT_PRG_CHANGE) { \
            flight_data = uart_data_decoder(uart_str_in); \
            led_update(flight_data); \
            clear_display(0, 1); \
            display_err_code(ERR_ASC_UNINITIALIZED); \
        } \
    } \
}

#define ASC_DISP_2_NUMS(prev, next) {\
    if((prev_verb == 13) && (prev_noun == prev)) { \
        SAVE_PREV_VERB_NOUN \
        led_stat[LED_STAT_DISP1] = true;\
        keypad_status = KEY_STAT_NO_CHANGE;\
        while(keypad_status != KEY_STAT_PROCEED) { \
            flight_data = uart_data_decoder(uart_str_in); \
            led_update(flight_data); \
            display_number(0, 1, flight_data.num1); \
            display_number(1, 0, flight_data.num2); \
            clear_display(1, 1); \
        } \
\
        led_stat[LED_STAT_DISP1] = false;\
        noun = next; \
        clear_display(0, 0); \
        add_alarm_in_ms(800, display_program, NULL, false); /* 800 ms blank, then display program */ \
        sleep_ms(900); \
    } else { \
        while(keypad_status != KEY_STAT_PRG_CHANGE) { \
            flight_data = uart_data_decoder(uart_str_in); \
            led_update(flight_data); \
            clear_display(0, 1); \
            display_err_code(ERR_ASC_UNINITIALIZED); \
        } \
    } \
}

#define ASC_DISP_3_NUMS(prev, next) {\
    if((prev_verb == 13) && (prev_noun == prev)) { \
        SAVE_PREV_VERB_NOUN \
        led_stat[LED_STAT_DISP1] = true;\
        keypad_status = KEY_STAT_NO_CHANGE;\
        while(keypad_status != KEY_STAT_PROCEED) { \
            flight_data = uart_data_decoder(uart_str_in); \
            led_update(flight_data); \
            display_number(0, 1, flight_data.num1); \
            display_number(1, 0, flight_data.num2); \
            display_number(1, 1, flight_data.num3); \
        } \
\
        led_stat[LED_STAT_DISP1] = false;\
        noun = next; \
        clear_display(0, 0); \
        add_alarm_in_ms(800, display_program, NULL, false); /* 800 ms blank, then display program */ \
        sleep_ms(900); \
    } else { \
        while(keypad_status != KEY_STAT_PRG_CHANGE) { \
            flight_data = uart_data_decoder(uart_str_in); \
            led_update(flight_data); \
            clear_display(0, 1); \
            display_err_code(ERR_ASC_UNINITIALIZED); \
        } \
    } \
}

#pragma clang diagnostic push
#pragma ide diagnostic ignored "EndlessLoop"

float insnms[3] = {0};
uint8_t asc_profile = 4;

bool timer_uart_send_handler(__unused struct repeating_timer *t);
void software_reset();

int main() {
    stdio_init_all();
    // Peripherals init
    keypad_init();
    led_init();
    max7219_init();
    spi_send_data(0, REG_SHUTDOWN, 0x01);
    spi_send_data(1, REG_SHUTDOWN, 0x01);
    // Connection with server init
    conn_init();

    // Welcome message
    welcome_message_print();

    // Try to handshake
    handshake:
    uart_handshake();

    verb = 0, noun = 0;
    prev_verb = 0, prev_noun = 0;
    display_two_digit_number(0, 0, 0, 0);
    display_two_digit_number(0, 0, 1, 0);

    // Timer for periodical sending data via UART init
    struct repeating_timer timer_uart_send;
    add_repeating_timer_ms(UART_SEND_PERIOD_MS, timer_uart_send_handler, NULL, &timer_uart_send);

    gpio_set_irq_enabled_with_callback(col[0], GPIO_IRQ_EDGE_RISE | GPIO_IRQ_EDGE_FALL, true, &keypad_irq_handler);
    for(register uint8_t i = 1; i < 4; i++) {
        gpio_set_irq_enabled(col[i], GPIO_IRQ_EDGE_RISE | GPIO_IRQ_EDGE_FALL, true);
    }

    gpio_put(LED_CON, true);
    
    while(true) {
        KSP_DATA flight_data = uart_data_decoder(uart_str_in);
        led_update(flight_data);

        switch (verb) {
        case 0:
            switch (noun) {
            // Disconnect from server
            case 1:
                clear_display(0, 1);
                clear_display(1, 0);
                clear_display(1, 1);

                cancel_repeating_timer(&timer_uart_send);
                time_since_last_connection = 6;
                flight_data = uart_data_decoder(UART_EMPTY_STRING);
                led_update(flight_data);

                memset(uart_str_in, 0, UART_STR_IN_BUF_SIZE);
                goto handshake;

                break;
            // Restart DSKY
            case 2:
                clear_display(0, 1);
                clear_display(1, 0);
                clear_display(1, 1);
                sleep_ms(500);
                software_reset();
                break;
                
            default:
                clear_display(0, 1);
                clear_display(1, 0);
                clear_display(1, 1);
                break;
            } 
            break;
        
        case 1:
            if(noun == 2) {
                SAVE_PREV_VERB_NOUN
                clear_display(0, 1);
                clear_display(1, 0);
                clear_display(1, 1);
                while (keypad_status != KEY_STAT_PRG_CHANGE) {
                    flight_data = uart_data_decoder(uart_str_in);
                    led_update(flight_data);
                    display_float_number(0, 1, (float)flight_data.num1 / 1000);
                    display_float_number(1, 0, (float)flight_data.num2 / 1000);
                    display_float_number(1, 1, (float)flight_data.num3 / 1000);
                }
            } else {
                SAVE_PREV_VERB_NOUN
                clear_display(0, 1);
                clear_display(1, 0);
                clear_display(1, 1);
                while (keypad_status != KEY_STAT_PRG_CHANGE) {
                    flight_data = uart_data_decoder(uart_str_in);
                    led_update(flight_data);
                    display_number(0, 1, flight_data.num1);
                    display_number(1, 0, flight_data.num2);
                    display_number(1, 1, flight_data.num3);
                }
            }
            break;

        case 2:
            if(noun == 6) {
                SAVE_PREV_VERB_NOUN
                clear_display(0, 1);
                clear_display(1, 0);
                clear_display(1, 1);
                while (keypad_status != KEY_STAT_PRG_CHANGE) {
                    flight_data = uart_data_decoder(uart_str_in);
                    led_update(flight_data);
                    display_float_number(0, 1, (float)flight_data.num1 / 1000);
                    display_float_number(1, 0, (float)flight_data.num2 / 1000);
                    display_float_number(1, 1, (float)flight_data.num3 / 1000);
                }
            } else if((noun >= 7) && (noun <= 9)) {
                SAVE_PREV_VERB_NOUN
                clear_display(0, 1);
                clear_display(1, 0);
                clear_display(1, 1);
                while (keypad_status != KEY_STAT_PRG_CHANGE) {
                    flight_data = uart_data_decoder(uart_str_in);
                    led_update(flight_data);
                    display_number(0, 1, flight_data.num1);
                    display_number(1, 0, flight_data.num2);
                    display_float_number(1, 1, (float)flight_data.num3 / 1000);
                }
            } else {
                SAVE_PREV_VERB_NOUN
                clear_display(0, 1);
                clear_display(1, 0);
                clear_display(1, 1);
                while (keypad_status != KEY_STAT_PRG_CHANGE) {
                    flight_data = uart_data_decoder(uart_str_in);
                    led_update(flight_data);
                    display_number(0, 1, flight_data.num1);
                    display_number(1, 0, flight_data.num2);
                    display_number(1, 1, flight_data.num3);
                }
            }
            break;

        case 3:
            if((noun == 2) || (noun == 3)) {
                SAVE_PREV_VERB_NOUN
                clear_display(0, 1);
                clear_display(1, 0);
                clear_display(1, 1);
                while (keypad_status != KEY_STAT_PRG_CHANGE) {
                    flight_data = uart_data_decoder(uart_str_in);
                    led_update(flight_data);
                    display_number(0, 1, flight_data.num1);
                    display_number(1, 0, flight_data.num2);
                    display_float_number(1, 1, (float)flight_data.num3 / 1000);
                }
            } else {
                SAVE_PREV_VERB_NOUN
                clear_display(0, 1);
                clear_display(1, 0);
                clear_display(1, 1);
                while (keypad_status != KEY_STAT_PRG_CHANGE) {
                    flight_data = uart_data_decoder(uart_str_in);
                    led_update(flight_data);
                    display_number(0, 1, flight_data.num1);
                    display_number(1, 0, flight_data.num2);
                    display_number(1, 1, flight_data.num3);
                }
            }
            break;

        case 4:
            if(noun == 3) {
                SAVE_PREV_VERB_NOUN
                clear_display(0, 1);
                clear_display(1, 0);
                clear_display(1, 1);
                while (keypad_status != KEY_STAT_PRG_CHANGE) {
                    flight_data = uart_data_decoder(uart_str_in);
                    led_update(flight_data);

                    float dv = (float)flight_data.num1 / 1000;
                    float rdv = (float)flight_data.num2 / 1000;

                    (dv < 10000) ? display_float_number(0, 1, dv) : display_number(0, 1, (int64_t)dv);
                    (rdv < 10000) ? display_float_number(1, 0, rdv) : display_number(1, 0, (int64_t)rdv);

                    display_number(1, 1, flight_data.num3);
                }
            } else if(noun == 4) {
                SAVE_PREV_VERB_NOUN
                clear_display(0, 1);
                clear_display(1, 0);
                clear_display(1, 1);
                while (keypad_status != KEY_STAT_PRG_CHANGE) {
                    flight_data = uart_data_decoder(uart_str_in);
                    led_update(flight_data);
                    display_number(0, 1, flight_data.num1);
                    display_number(1, 0, flight_data.num2);
                    display_float_number(1, 1, (float)flight_data.num3 / 1000);
                }
            } else {
                SAVE_PREV_VERB_NOUN
                clear_display(0, 1);
                clear_display(1, 0);
                clear_display(1, 1);
                while (keypad_status != KEY_STAT_PRG_CHANGE) {
                    flight_data = uart_data_decoder(uart_str_in);
                    led_update(flight_data);
                    display_number(0, 1, flight_data.num1);
                    display_number(1, 0, flight_data.num2);
                    display_number(1, 1, flight_data.num3);
                }
            }

            break;
        
        case 5:
            if((noun == 1) || (noun == 2)) {
                SAVE_PREV_VERB_NOUN
                clear_display(0, 1);
                clear_display(1, 0);
                clear_display(1, 1);
                while (keypad_status != KEY_STAT_PRG_CHANGE) {
                    flight_data = uart_data_decoder(uart_str_in);
                    led_update(flight_data);
                    display_number(0, 1, flight_data.num1);
                    display_float_number(1, 0, (float)flight_data.num2 / 1000);
                    display_float_number(1, 1, (float)flight_data.num3 / 1000);
                }
            } else {
                SAVE_PREV_VERB_NOUN
                clear_display(0, 1);
                clear_display(1, 0);
                clear_display(1, 1);
                while (keypad_status != KEY_STAT_PRG_CHANGE) {
                    flight_data = uart_data_decoder(uart_str_in);
                    led_update(flight_data);
                    display_number(0, 1, flight_data.num1);
                    display_number(1, 0, flight_data.num2);
                    display_number(1, 1, flight_data.num3);
                }
            }
            break;

        // Basic ship control
        case 12:                
            // Init node creation
            if(noun == 30) {
                sleep_ms(1000);
                SAVE_PREV_VERB_NOUN
                send_data[0] = -2; 
                send_data[1] = -2; 
                send_data[2] = -2; 
                noun = 31;
                clear_display(0, 0);
                add_alarm_in_ms(800, display_program, NULL, false); // 800 ms blank, then display program
                sleep_ms(900);
            // Insert UT - year, day
            } else if(noun == 31) {
                NOD_INS_2_NUMS(30)
            // Display UT - year, day
            } else if(noun == 32) {
                NOD_DISP_2_NUMS(31)
            // Insert UT - hour, minute, second
            } else if(noun == 33) {
                NOD_INS_3_NUMS(32)
            // Display UT - hour, minute, second
            } else if(noun == 34) {
                NOD_DISP_3_NUMS(33)
            // Insert prograde, normal and radial Delta v
            } else if(noun == 35) {
                NOD_INS_3_NUMS(34)
            // Display prograde, normal and radial Delta v
            } else if(noun == 36) {
                NOD_DISP_3_NUMS(35)
            // Confirm node creation
            } else if(noun == 37) {
                if((prev_verb == 12) && (prev_noun == 36)) {
                        led_stat[LED_STAT_DISP1] = true;
                        clear_display(0, 1);
                        clear_display(1, 0);
                        clear_display(1, 1);

                        send_data[0] = -2;
                        send_data[1] = -2;
                        send_data[2] = -2;

                        while(keypad_status != KEY_STAT_PROCEED) {
                            flight_data = uart_data_decoder(uart_str_in);
                            led_update(flight_data);
                        }

                        send_data[0] = 1;
                        sleep_ms(1500);

                        verb = 4;
                        noun = 3;

                        led_stat[LED_STAT_DISP1] = false;
                        clear_display(0, 0);
                        add_alarm_in_ms(800, display_program, NULL, false); // 800 ms blank, then display program
                        sleep_ms(900);
                    } else {
                        while(keypad_status != KEY_STAT_PRG_CHANGE) {
                            flight_data = uart_data_decoder(uart_str_in);
                            led_update(flight_data);
                            clear_display(0, 1);
                            display_err_code(ERR_NOD_UNINITIALIZED);
                        }
                    }
            } else {
                sleep_ms(1500);
                verb = prev_verb;
                noun = prev_noun;
                clear_display(0, 0);
                add_alarm_in_ms(800, display_program, NULL, false); // 800 ms blank, then display program
            }

            break;
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

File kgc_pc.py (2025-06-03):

import krpc
import serial

serial_port = input("Serial port? ")
ser_conn = serial.Serial(serial_port, 115200)
ser_conn.bytesize = serial.EIGHTBITS
ser_conn.stopbits = serial.STOPBITS_ONE
ser_conn.parity = serial.PARITY_EVEN
ser_conn.timeout = None

krpc_conn = krpc.connect(name='KGC 0.02')
if ser_conn.is_open == False:
    ser_conn.open()

tst = 1024
verb = 0
noun = 0

while True:
    ser_in = ser_conn.readline()
    ser_str = ser_in.decode("utf-8", "strict")
    ser_in_str = ser_str.strip()
    ser_in_list = ser_str.split(';')
    print(ser_str)

    for i in ser_in_list:
        if i.startswith("V:"):
            verb = i.split(':')
            verb = verb[1].strip()
            verb = int(verb)
        elif i.startswith("N:"):
            noun = i.split(':')
            noun = noun[1].strip()
            noun = int(noun)
        print("Verb is ", verb, ", noun is ", noun)

    if str(krpc_conn.krpc.current_game_scene) == "GameScene.flight": # type: ignore
        vessel = krpc_conn.space_center.active_vessel # type: ignore
        match verb:
            # Verb 1 = Display flight info
            case 1:
                match noun:
                    # Noun 1 = Altitude above sea level + Apoapsis + Periapsis
                    case 1:
                        ser_out_str = str(int(vessel.flight().mean_altitude)) + ";" + str(int(vessel.orbit.apoapsis_altitude)) + ";" + str(int(vessel.orbit.periapsis_altitude))
                        ser_out = ser_out_str.encode("utf-8")
                        ser_conn.write(ser_out)
            # Testing output
            case 2:
                ser_out_str = str(tst) + "\n"
                ser_out = ser_out_str.encode("utf-8")
                ser_conn.write(ser_out)
                tst += 1

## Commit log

2022-02-14 Added schematic and PCB files
    [kgc.kicad_pcb, kgc.kicad_sch]
2022-03-06 New program switching system, support for LED indicators and buzzer, clear_display now clears individual displays, electrical schematic improvements
    kgc.c:
    - New macros for LEDs and buzzer GPIO pins.
    - New function led_init for initializing LEDs and buzzer GPIOs.
    - Section and command system was replaced by verb and nouns (yes, I robed it from AGC). Verbs are commands, nouns are relatively independent parameters for verbs (mostly kind of displayed data) . Verbs are executed by core 0 in main, nouns by core1 in core1_entry.
    - Verbs list:
    - 00 for no operation
    - 01 for display data only
    - 99 for device test
    - Nouns list:
    - 00 for no operation
    - 01 for stopwatch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
    [kgc.kicad_pcb, kgc.kicad_sch]
2025-06-01 Major updates
    Updated SDK version (2.1.1)
    - Almost everything was deleted - code was trash and I forgot how it works.
    - In main function is for now only some testing code.
    - New welcome message after device starts. xD
    max7219.(h/c):
    - New character (K) in code table.
    keypad.(h/c):
    - Magic numbers reduction in key_evaluate functions (and new macros in connection with that).
    - Change in connection with code table update.
    - Correction key defined (not currently used).
    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
    [keypad.c, kgc.c, max7219.c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]
2025-06-02 Added communication with KSP :poggies:
    New (.c/.h) files for UART communication with PC, new Python program for communication between KSP and KGC.
    KGC is now able to show altitude, apoapsis and periapsis through Verb 1, Noun 1.
    Still pretty buggy, Python program crashes when there isn't any active vessel. :)
    [connection.c, kgc.c, kgc_pc.py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]
2025-06-02 Added KiCad project files
    [kgc.kicad_pcb]
2025-06-03 Fixed python program crashing when game scene isn't flight, code cleanup
    [kgc_pc.py]
2025-06-03 New handshake, kgc_pc is now kgc_server, several smaller changes
    kgc_server.py, kgc.c:
    - Handshake implementated (now KGC must send message to server and server must answer on the beggining of communication)
    - New verb 99 for output testing:
    - Noun 01 for displays test
    - Noun 02 for test of communication with server (KGC is receiving 1 incrementing number from server)
    connection.(h/c):
    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
2025-06-03 Updated CMakeList for led.(h/c)
2025-06-04 Defined format of UART string
    - New struct for data from server
    - New uart_data_decoder() function for decoding UART input string
    - kgc.c:
    - String decoding delecated to uart_data_decoder() function.
    - Switch for Verb 1's Nouns replaced by simple if - else
    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
    [connection.c, keypad.c, kgc.c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]
2025-06-04 Support for FLD, SAS, RCS, GEA and BRK LEDs, info about game pause added to UART string
    - Sending data period now defined by macro and reduced to 250 ms
    - Added support for information about paused game
    led.(h/c):
    - New functions for update LEDs state from KSP_DATA struct
    kgc_server.py:
    - Added support for information about paused game
    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
2025-06-05 New nouns for monitoring resources, blinking LEDs when resources are running out
2025-06-05 New Verbs/Nouns for take off and landing
2025-06-06 Several updates
    - Support for displaying float numbers
    - Several Verbs/Nouns displayed as floats
    - Reduced SPI baudrate
    - Changed time format
    - Fixed server crashing when V:1;N:9/10 and no SoI change
    - New verb 4 for next maneuver informations
    - Small improvements
    [kgc.c, kgc_server.py, max7219.c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]
2025-06-06 Fixed bug in V:5;N:1
    [kgc.c]
2025-06-08 Added check for maximum length of inserted string
2025-06-11 Updated docs
    [ascent_truth_table.csv, verb_noun_list.csv]
2025-06-11 Higher SPI baudrate, Verb & Noun is now blinking when DSKY waits for confirm
2025-06-13 README update, typos correction
    [kgc.c, kgc_server.py]
2025-06-15 Node creation, small fixes
    [verb_noun_list.csv]

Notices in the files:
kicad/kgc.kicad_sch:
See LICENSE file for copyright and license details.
